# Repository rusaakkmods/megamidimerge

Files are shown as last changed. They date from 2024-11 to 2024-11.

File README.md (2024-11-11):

# rusaaKKMODS Megamidi Merge
================

A MIDI merge project for Arduino.

## Overview
-----------

This project is designed to merge MIDI input from multiple sources, calculate beats per minute (BPM), and update clock resolution as needed.

### Features
------------

* Merges MIDI input from two sources (MIDI-1 and MIDI-2)
* Calculates BPM from MIDI clock messages
* Updates clock resolution based on user input
* Displays current BPM, clock resolution, and master clock source on an OLED display

### Functions
-------------

* `initMidi()`: Initializes MIDI input and output interfaces.
* `calculateBPM()`: Calculates the current BPM from MIDI clock messages.
* `changeClockResolution()`: Updates the clock resolution based on user input.
* `readMidiInput()`: Reads and processes MIDI input from both sources.
* `printDisplay()`: Prints the current display information, including master clock source, BPM, and clock resolution.
* `isMasterInput1()`: Checks if the master clock source is set to MIDI-1.
* `loop()`: The main loop function that updates BPM, checks for user input, and reads MIDI input.

### Dependencies
------------

* Arduino library (for `millis()` and `digitalRead()` functions)
* MIDI library (for MIDI input and output handling)

### Hardware Requirements
----------------------

* Arduino board (e.g. Arduino Mega)
* MIDI input and output interfaces
* OLED display
* Push button for changing clock resolution

### Usage
-----

1. Upload the sketch to the Arduino board.
2. Connect the MIDI input and output interfaces to the board.
3. Connect the OLED display to the board.
4. Press the push button to change the clock resolution.

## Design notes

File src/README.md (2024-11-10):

Based on the code we currently have, let's review the main goals and assess the progress:

### Main Goals:

1. **Core Function: Merges MIDI data from two MIDI inputs and sends it to MIDI output**

   - **Status**: Achieved. The code reads MIDI messages from `MIDIINPUT1` and `MIDIINPUT2` and merges them into a single output (`MIDIOUTPUT`). MIDI messages are forwarded appropriately to combine data from both inputs.

2. **Master Clock Selection: An SPDT switch allows you to choose which MIDI input provides the master clock**

   - **Status**: Achieved. The function `isMasterInput1()` reads the state of the master switch (`MASTER_SWITCH_PIN`) to determine which MIDI input is the master clock source. This condition is used throughout the code to determine the active master.

3. **Analog Clock Output: Generates an analog clock signal synchronized with the MIDI clock**

   - **Status**: Achieved. The function `generateDigitalClockPulse()` is responsible for outputting a pulse on the clock output pin (`CLOCK_OUT_PIN`). However, software-based timing could be less precise, and switching to hardware-based timers for pulse generation is recommended.

4. **Clock Pulse Rate: A knob to control the clock pulse per quarter note (1 to 24 ppqn) for the analog clock output**

   - **Status**: Achieved. The knob input (`RESOLUTION_KNOB_PIN`) is read and mapped to different pulse-per-quarter-note values using the `handleClockOut()` function. The mapped values are snapped to specific options, which align with the requirements.

5. **Active Master Input Display: Shows the active MIDI Input acting as the Master Clock on an OLED display**

   - **Status**: Achieved. The function `printDisplay()` updates the OLED display with information about which input is the active master, depending on the `isMasterInput1()` function result. It also displays BPM and clock rate settings.

6. **BPM Display: Displays the Beats Per Minute (BPM) in 4/4 time signature based on selected master clock**

   - **Status**: Achieved. The function `calculateBPM()` calculates the BPM based on the `clockCount`, and `handleDisplay()` updates the OLED display every second with the calculated BPM.

7. **Clock Rate Display: based on the selected resolution setting**

   - **Status**: Achieved. The function `printDisplay()` shows the clock rate and provides an indicator for the current pulse-per-quarter-note value. The `resolution` variable is used for determining and displaying the current setting.

8. **Analog Clock Input: Override MIDI master clock**

   - **Status**: Achieved. The `handleClockIn()` function manages clock input detection. When a clock pulse is detected on `CLOCK_IN_PIN`, it sets `clockInputPulse` and sends a MIDI clock message (`sendRealTimeMessage(midi::Clock)`), effectively overriding the MIDI master clock.

### &#x20;Features:

1. **2 MIDI Inputs (as Input 1 and Input 2)**

   - **Status**: Achieved. The code uses `Serial1` and `Serial2` as MIDI inputs, which are then processed and forwarded as needed.

2. **2 MIDI Thru (from MIDI Input 1 and MIDI Input 2)**

   - **Status**: Implicitly Achieved. The messages from `MIDIINPUT1` and `MIDIINPUT2` are forwarded, effectively acting as MIDI Thru functionality.

3. **A MIDI Output (Merged from both MIDI Inputs)**

   - **Status**: Achieved. The merged MIDI messages are sent to `MIDIOUTPUT`.

4. **A 3.5mm TRS Socket as a second MIDI Output (independent copy of the first MIDI Output)**

   - **Status**: Not explicitly mentioned in the code. If this feature is still desired, it may need additional implementation, likely involving copying the `MIDIOUTPUT` to another UART or pin.

5. **Analog Clock Out based on Master clock**

   - **Status**: Achieved. The clock output is generated using software-based timing (`generateDigitalClockPulse()`), but improvements to use hardware timers are recommended for better precision.

6. **Analog Clock In that overrides the MIDI Clock when plugged**

   - **Status**: Achieved. The `handleClockIn()` function detects clock input pulses and overrides the MIDI clock when active.

7. **A Master Clock switch between Input 1 or Input 2**

   - **Status**: Achieved. The function `isMasterInput1()` reads the `MASTER_SWITCH_PIN` to determine which input is the master clock.

8. **A Knob to control Clock Out PPQN**

   - **Status**: Achieved. The `RESOLUTION_KNOB_PIN` is used to set the clock rate (`resolution`), which affects the pulse-per-quarter-note value.

9. **USB should power the system and should be recognized by Computer as MIDI Device transmitting merged MIDI Output**

   - **Status**: Not explicitly Achieved. The code does not mention USB MIDI functionality. To achieve this, additional USB-MIDI code would need to be implemented to allow the Arduino to act as a USB MIDI device.

10. **An OLED Display to view Active Master information**

    - **Status**: Achieved. The `printDisplay()` function displays the current master clock source, BPM, and clock rate settings on the OLED.

### Summary of Improvements:

- **Precision for Clock Output**: Consider using hardware timers for generating clock pulses (`generateDigitalClockPulse()`) to improve accuracy.
- **USB MIDI Functionality**: If USB MIDI is required, additional implementation is necessary.
- **Refactor Complex Functions**: Functions like `forwardMessage()` are handling many different cases, and breaking them into smaller functions would improve readability and maintainability.
- **Analog Read Noise Filtering**: Adding noise filtering or averaging to `analogRead(RESOLUTION_KNOB_PIN)` can help stabilize the value and avoid erratic changes in clock rate.

Overall, the core functionality has been achieved, with some areas for improvement in terms of precision, maintainability, and additional desired features like USB MIDI support.

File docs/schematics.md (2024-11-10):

### Bill of Materials (BOM):

1. **Arduino Mega 2560 Pro**

   - Quantity: 1
   - Acts as the main controller.

2. **5-pin DIN MIDI Ports**

   - Quantity: 6&#x20;
   - for 2 MIDI Inputs, 2 MIDI Thru, 2 MIDI Outputs

3. **3.5mm TRS Jack**

   - Quantity: 2
   - for MIDI Outputs

4. **6N137 Optocoupler**

   - Quantity: 2&#x20;
   - for MIDI Input isolation

5. **Current-Limiting Resistors**

   - 220 ohms: Quantity: 4 (MIDI Input LED and Output TX)
   - 10k ohms: Quantity: 2 (Optocoupler pull-up)

6. **LM393 Comparator or 74HC14**

   - Quantity: 1 (for Analog Clock pulse generation)

7. **OLED Display (128x32, I2C)**

   - Quantity: 1
   - Used to display active master, BPM, etc.

8. **Potentiometer (for PPQN Selection)**

   - Quantity: 1
   - Type: 10k linear potentiometer

9. **SPDT Switch**

   - Quantity: 1
   - Type: Toggle or slide switch

10. **TS Jack (for Analog Clock Input)**

    - Quantity: 1

11. **Capacitors**

- 100µF: Quantity: 1 (Power Supply Stabilization)
- 0.1µF Ceramic: Quantity: 4 (Decoupling capacitors for ICs)

11. **PWM Output Components**

- **Voltage Divider Resistors**: Various values depending on desired voltage.
- **Comparator Potentiometer**: Quantity: 1 (to set threshold for LM393)

12. **Miscellaneous**

- **Wires**: Jumper wires for connections.
- **Breadboard**: Optional, for prototyping.
- **Pull-up Resistors**: Quantity: 2 (10k ohms for switches).

### Components in the Project:

1. **Arduino Mega 2560 Pro**:

   - Acts as the main controller.
   - Handles MIDI inputs, MIDI merging, and MIDI output.

2. **MIDI Ports (DIN connectors or TRS jacks)**:

   - **MIDI Input 1** and **MIDI Input 2**: Receive MIDI signals.
   - **MIDI Thru 1** and **MIDI Thru 2**: Allow direct forwarding of incoming MIDI signals.
   - **MIDI Output**: Outputs the merged MIDI messages.

3. **MIDI Input Circuit**:

   - Typically involves **6N137** optocouplers for MIDI signal isolation.
   - **Current-limiting resistors** are needed for safe data transmission.

4. **Analog Clock Circuit**:

   - Outputs clock signals synchronized with the master MIDI clock.
   - **LM393 comparator** or **74HC14** for generating pulses, using the analog clock signal.

5. **OLED Display (I2C, 128x32)**:

   - Used for displaying the active master, BPM, clock rate, etc.
   - Connected through I2C using **SCL** and **SDA** pins.

6. **Knob for PPQN Selection (Potentiometer)**:

   - Used to select the clock rate.
   - **Connected to an analog input** of the Arduino for reading the resistance value.

7. **SPDT Switch for Master Clock Selection**:

   - Switches between MIDI Input 1 and MIDI Input 2 as the clock source.
   - Connected to a digital input.

8. **Clock Input Circuit**:

   - Analog clock input that overrides the MIDI clock.
   - **TS jack** with clock input detection and routing.
   - Typically uses an interrupt for detecting pulses.

### Detailed Schematic Overview:

#### 1. **Arduino Mega 2560 Pro**:

- **Power Supply**: USB or external power supply. Make sure to add capacitors (e.g., 100µF and 0.1µF) for stability.
- **MIDI Ports**:
  - **MIDI Input**: Connect each input through a 220-ohm resistor to the anode of an LED (inside a 6N137 optocoupler). The cathode of the LED goes to ground via a current-limiting resistor (typically 220 ohms). The 6N137 output is pulled up (typically 10k ohms) and then connected to the Arduino RX pin.
  - **MIDI Output**: The output from the Arduino TX pin goes through a 220-ohm resistor to pin 4 of the MIDI output connector, with pin 5 connected to ground.

#### 2. **MIDI Input Circuit** (using **6N137** optocouplers):

- **6N137 Pin Configuration**:
  - **Pin 1**: Vcc (connected to 5V through a current-limiting resistor)
  - **Pin 2 (Anode)**: Connected to MIDI Input through a 220-ohm resistor.
  - **Pin 3 (Cathode)**: Connected to GND.
  - **Pin 4 (GND)**: Connected to GND.
  - **Pin 5 (Output)**: Connected to Arduino RX pin, pulled up to 5V through a 10k resistor.
  - **Pin 6 (NC)**: Not connected.
  - **Pin 7 (Vcc)**: Connected to 5V.
  - **Pin 8 (GND)**: Connected to GND.

#### 3. **OLED Display**:

- **SDA**: Connected to Arduino **SDA** (typically A4 for Mega).
- **SCL**: Connected to Arduino **SCL** (typically A5 for Mega).
- **VCC**: Connected to 3.3V or 5V.
- **GND**: Connected to GND.

#### 4. **Knob for PPQN Selection**:

- **Potentiometer**:
  - One terminal to **GND**.
  - One terminal to **5V**.
  - The wiper (middle terminal) to an analog input pin (e.g., **A0**).

#### 5. **SPDT Switch**:

- One side connected to **5V**.
- The other side connected to **GND**.
- The middle pin is connected to a digital input pin (e.g., **D7**), with a **pull-up resistor** enabled to detect the switch state.

#### 6. **Analog Clock Input Circuit**:

- **TS Socket Pinout**:
  - **Tip**: Clock input signal.
  - **Ring**: Connect to **Tip** when unplugged to detect.
  - **Sleeve**: Ground.
- The **Tip** is connected to the **CLOCK\_IN\_PIN** via a current-limiting resistor, with an **interrupt** configured on this pin to detect rising edges.
- The **Ring** is used to detect if the clock is plugged in by connecting it to an additional digital pin that can be read.

#### 7. **Analog Clock Output Circuit**:

- **PWM Output (Pin 10)**: Use this pin to generate an analog voltage that is converted to pulses using a comparator.
- **Comparator LM393**:
  - **Non-inverting Input (+)**: Connected to the **PWM output pin** through a voltage divider.
  - **Inverting Input (-)**: Set with a threshold voltage using a potentiometer or resistor divider.
  - **Output**: Generates the clock pulse based on the threshold comparison.
- The output is then connected to the **Clock Out** TS socket.

### General Tips:

- **Power Rails**: Ensure decoupling capacitors are placed near every IC to reduce noise (e.g., 0.1µF ceramic capacitors).
- **Grounding**: Make sure all ground connections are common to avoid ground loops that can introduce noise.
- **Pull-up/Pull-down Resistors**: Properly use pull-up or pull-down resistors where required to ensure the stability of input signals, such as the switch or plug detection.

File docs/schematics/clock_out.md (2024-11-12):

### Review of Clock Output Schematic

#### **MEGA PIN 10 Connection**:
- The clock signal from **MEGA PIN 10** is correctly fed into the circuit, passing through **R19 (10kΩ)**, which acts as a current-limiting resistor. This is appropriate for preventing potential current surges into the next stage.

#### **Capacitor (C13 - 1µF)**:
- **C13 (1µF)** is placed in series after **R19** and connected to **GND** via **R20 (10kΩ)**, forming an RC filter.
- This configuration helps eliminate any noise in the clock signal before it is passed to the **74HC14** Schmitt Trigger, ensuring a stable and clean clock signal.
- The **1µF capacitor** and the **10kΩ resistor (R20)** give a cutoff frequency of approximately **16 Hz**, which should be effective for filtering out high-frequency noise without affecting the clock pulse.

#### **Schmitt Trigger Inverters (U4E, U4F - 74HC14)**:
- The **74HC14** Schmitt Trigger is used here, with **U4E** and **U4F** used for conditioning the clock signal.
- The clock signal is fed into **U4E**, which outputs a clean, inverted pulse. This signal is then sent to **J11 (Clock Out 1)** through **R21 (220Ω)**.
- The same input signal is also fed to **U4F**, which provides an additional clean output to **J12 (Clock Out 2)** through **R22 (220Ω)**.
- Using the **74HC14** for clock conditioning is an excellent choice, as it ensures a crisp, debounced clock pulse suitable for driving external clock inputs.

#### **Clock Output Jacks (J11, J12)**:
- **J11** and **J12** are used for clock outputs, each being fed from one of the Schmitt Trigger outputs through the corresponding output resistor (**R21** and **R22**, both **220Ω**).
- The **Tip (T)** of each jack is driven by the respective Schmitt Trigger output, while the **Sleeve (S)** is connected to **GND**.
- The **TN** connection on each jack is left unconnected, which is fine as it’s not needed for the clock signal.
- This setup is suitable for providing two identical clock signals, with **74HC14** outputs ensuring that they are clean and debounced.

### **Suggestions for Improvement**:

1. **Pull-down Resistors on Schmitt Trigger Inputs**:
   - It might be beneficial to add small pull-down resistors (e.g., **10kΩ**) to the inputs of **U4E** and **U4F** to ensure that they remain at a defined logic level if the input signal from **MEGA PIN 10** becomes disconnected. This helps prevent the Schmitt Trigger from floating, which could lead to unpredictable behavior.

### **Summary**:
- The schematic design is **correct** and should work effectively for generating two clock outputs from **MEGA PIN 10**.
- The use of **R19**, **C13**, and **R20** to filter the input and the **74HC14** Schmitt Trigger to clean up the clock signal are well-considered.
- Adding **pull-down resistors** to the **74HC14** inputs would further improve the reliability and robustness of the circuit.

This design is well-structured and should provide stable clock outputs. Let me know if you need further assistance or modifications!

Modifications:
Based on your updated schematic, here is my review:

1. **Component Placement and Value**:
   - The capacitors C14 and C15 (10nF) are well-placed for filtering purposes, which helps reduce noise and ensures stable clock output. Using these capacitors to filter the signal before it reaches the 74HC14 input and before driving the MIDI connectors is a good practice.
   - The resistor values seem correct for this type of application, particularly for providing current limiting to the outputs and pull-down where needed.

2. **74HC14 Usage**:
   - The 74HC14 Schmitt Trigger inverter (U4E and U4F) is appropriate here, as it will help to clean up the incoming signal from the Mega pin and ensure it has proper transitions. The Schmitt Trigger is ideal to eliminate noise from the clock pulse and ensure a stable square wave for the MIDI Clock output.

3. **Clock Outputs (J11 and J12)**:
   - The use of 220Ω resistors (R21 and R22) before the MIDI output connectors is good for limiting current, which helps to protect the 74HC14 output and meet MIDI current specifications.

4. **Decoupling Capacitors**:
   - Adding decoupling capacitors close to the power pins of the 74HC14 would be a good improvement if not already present. Typically, a 0.1 µF capacitor between Vcc and GND pins helps to filter any noise on the power line, ensuring reliable operation of the IC.

5. **Potential Improvement**:
   - Ensure that C13 (1µF) and R19/R20 (both 10kΩ) are appropriately tuned to avoid any unintended delay or filtering of the clock pulse. The RC combination acts as a filter, so it's important that the values are selected to preserve the desired pulse timing characteristics.
   - The capacitors C14 and C15 (10nF) also add filtering at the output. Just make sure they are tuned in such a way that the pulse shape still matches what you need for MIDI communication, which requires fast transitions.

The overall design looks well-planned for a reliable MIDI clock output circuit. Just consider double-checking the timing to make sure that none of the RC filtering affects the precision of the clock signal that’s critical in MIDI timing.

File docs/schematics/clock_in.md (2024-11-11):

### Review of Updated Clock In Schematic

This updated schematic looks well-optimized and includes all the important elements for both input protection and reliable plug detection. Here’s a review:

#### **Jack (J10 - Clock In)**:
- The **Tip (T)** is correctly connected to **MEGA PIN 3** through **R18**.
- **Sleeve (S)** is connected to **GND** for proper grounding, and **TN** is also connected to **T** when unplugged, which allows for plug detection functionality.
  
#### **Current Limiting Resistor (R18 - 220Ω)**:
- The addition of **R18 (220Ω)** in series between **pin T** of **J10** and **MEGA PIN 3** is an excellent addition for protecting **MEGA PIN 3** from any excessive current.
- This provides the necessary safety without affecting the functionality of clock pulse detection.

#### **Voltage Divider for Plug Detection (R16, R17)**:
- **R17 (10kΩ)** and **R16 (10kΩ)** form a voltage divider providing a stable reference voltage for **MEGA PIN A1**.
- This is sufficient to differentiate between the plug being connected and disconnected, allowing the microcontroller to detect the plug status reliably.

#### **Noise Filtering Capacitor (C12 - 0.1µF)**:
- **C12 (0.1µF)** is placed correctly between the voltage divider and **GND**, helping to eliminate high-frequency noise and ensuring stable readings on **MEGA PIN A1**.

### **Suggestions**:
- The current configuration now provides the necessary safety (via **R18**) and a stable voltage reference for plug detection.
- Ensure the voltage at **MEGA PIN A1** is well-tested to confirm it provides consistent readings under both conditions (plug connected vs. disconnected). The **10kΩ** resistors should work well, but testing might indicate if a slight adjustment is needed.

### **Summary**:
- The addition of **R18 (220Ω)** makes this schematic well-protected.
- The plug detection functionality is intact, with **R16**, **R17**, and **C12** providing stable operation.
- This circuit now effectively protects the microcontroller inputs and reliably differentiates between plug states.

This design should be ready for implementation. Great work! If you need further assistance or modifications, feel free to ask!

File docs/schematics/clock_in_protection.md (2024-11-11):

### Clock In Surge Protection Improvement

To add safety measures for the **Clock In (J10)** circuit to protect against high currents and voltage spikes, we have made the following improvements:

#### **Components and Their Values**:
- **J10 (Clock In Jack)**: The input jack for external clock signals.
- **R18**: **220Ω current limiting resistor** in series.
- **D1 (1N5819 Schottky Diode)**: To clamp any overvoltage to **GND**.
- **D2 (1N5819 Schottky Diode)**: To clamp any overvoltage to **5V**.
- **F1**: **50mA polyfuse** for overcurrent protection.

#### **Detailed Schematic Pinout Routing**:

1. **Clock In Jack (J10)**:
   - **Pin T (Tip)** of **J10**:
     - **Connect to R18** (220Ω current limiting resistor).
   - **Pin S (Sleeve)** of **J10**:
     - **Connect to GND**.
   - **Pin TN (if present, not used for routing)**.

2. **Current Limiting Resistor (R18 - 220Ω)**:
   - **One end connected to Pin T** of **J10**.
   - **The other end connected to MEGA PIN 3**.
   - This resistor limits the current flowing into **MEGA PIN 3**.

3. **Polyfuse (F1 - 50mA)**:
   - **Connect F1 in series** with **R18** between **Pin T** and **MEGA PIN 3**.
   - This provides protection against sustained overcurrent.

4. **Schottky Diodes (D1 and D2 - 1N5819)**:
   - **D1**: Voltage Clamping to **GND**:
     - **Anode** of **D1** connected to **GND**.
     - **Cathode** of **D1** connected to the node where **R18** and **F1** connect to **MEGA PIN 3**.
     - This clamps any negative voltage spikes to protect **MEGA PIN 3**.
   - **D2**: Voltage Clamping to **+5V**:
     - **Anode** of **D2** connected to the node where **R18** and **F1** connect to **MEGA PIN 3**.
     - **Cathode** of **D2** connected to **+5V**.
     - This clamps any voltage above **5V** to the **5V rail**, protecting **MEGA PIN 3** from overvoltage.

5. **MEGA PIN 3**:
   - The connection from **R18** (after going through the **polyfuse**) connects to **MEGA PIN 3** for **clock pulse detection**.
   - **MEGA PIN 3** should also be configured as an **input** with either an internal or external **pull-up resistor** to maintain a stable state when no signal is connected.

#### **Explanation**:
- **R18 (220Ω)**: Limits the current from **pin T** of **J10** to **MEGA PIN 3**, ensuring the current remains within safe limits.
- **F1 (50mA Polyfuse)**: Provides overcurrent protection and disconnects the circuit if a sustained overcurrent condition occurs.
- **D1 (1N5819)**: Protects **MEGA PIN 3** from any **negative voltage spikes** by clamping to **GND**.
- **D2 (1N5819)**: Protects **MEGA PIN 3** from **positive overvoltage** spikes above **5V** by clamping to the **5V rail**.

#### **Summary**:
- The **current limiting resistor (R18)** and **polyfuse (F1)** together ensure that **MEGA PIN 3** is protected against high current conditions.
- The **Schottky diodes (D1 and D2)** provide protection against overvoltage and negative voltage spikes, clamping the signal to a safe range.
- This setup adds robustness to the **Clock In** circuitry and helps to prevent damage to the microcontroller.

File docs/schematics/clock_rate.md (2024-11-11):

### Clock Rate Knob Review

Clock Rate Knob Schematic

#### **Review of the Updated Clock Rate Knob**:

1. **Potentiometer (RV1) Configuration**:
   - The **10kΩ linear potentiometer (RV1)** is still correctly configured as a **voltage divider** between **+5V (Pin 3)** and **GND (Pin 1)**.
   - The **wiper (Pin 2)** is connected to **MEGA PIN A0**, providing a variable voltage to be read by the Arduino.

2. **Bypass Capacitor (C8)**:
   - You have added a **0.1µF capacitor (C8)** between the **wiper (Pin 2)** and **GND**. This is a great addition for filtering out any noise.
   - This capacitor acts as a **low-pass filter**, smoothing the signal read by **MEGA PIN A0**. It will reduce any high-frequency noise and provide a more stable analog voltage, thereby improving the accuracy of the clock rate adjustments.

3. **Voltage Range and Stability**:
   - With the **bypass capacitor (C8)** in place, the voltage range remains from **0V to 5V**, and the capacitor helps in filtering any small fluctuations, which results in a much more stable output to **MEGA PIN A0**.

#### **Suggestions for Further Improvement**:

- **Potentiometer Quality**:
  - Ensure the **potentiometer** used is of good quality, with smooth rotation and minimal contact noise, to avoid jitter in the clock rate readings.

- **PCB Layout Considerations**:
  - Place the **capacitor (C8)** as close as possible to **MEGA PIN A0** and the potentiometer's wiper pin to minimize the length of the trace, which will help reduce noise pickup.

#### **Summary**:

- The addition of the **0.1µF capacitor (C8)** is an excellent improvement. It provides a smoother analog signal, reducing noise and jitter in the clock rate adjustment.
- This configuration, with the potentiometer as a **voltage divider** and the **bypass capacitor**, should provide reliable and stable clock rate control for your MIDI device.

Overall, this updated design should function very well for adjusting the clock rate with minimal noise and jitter. Great work on incorporating the suggested improvement!

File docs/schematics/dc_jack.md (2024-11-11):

### DC Input Schematic Review

DC Input Schematic

#### **Review of the DC Input Schematic**:

1. **DC Jack (J9) Configuration**:
   - The **DC Jack (J9)** is appropriately labeled for **9V DC input**.
   - **Pin 1** (center positive) is correctly routed through the **fuse (F1)** and **Schottky diode (D11)** to the **VIN pin** of the Arduino MEGA.
   - **Pin 2** (outer sleeve) is connected to **GND**, completing the power connection.

2. **Protection Components**:
   - **Fuse (F1 - 1A)**:
     - The **fuse** is correctly placed in series with the positive terminal of the DC jack. This provides overcurrent protection and ensures the circuit is safeguarded from short circuits or excessive current draw.
   - **Schottky Diode (D11 - 1N5819)**:
     - The **Schottky diode** is in the correct orientation, with the **anode** connected to the positive terminal of the DC jack and the **cathode** connected to the **VIN** pin of the MEGA.
     - This configuration provides **reverse polarity protection** in case the DC adapter is accidentally connected with incorrect polarity. The **1N5819** is a good choice, as it has a low forward voltage drop, reducing power loss.

3. **Decoupling Capacitors**:
   - **Capacitor C10 (0.1µF Ceramic)**:
     - This capacitor is correctly placed across **VIN** and **GND**. It is effective at filtering out high-frequency noise.
   - **Capacitor C11 (100µF Electrolytic)**:
     - This capacitor is also correctly placed across **VIN** and **GND**, providing good low-frequency filtering and helping to smooth out the voltage from the DC adapter.
   - The combination of **C10** and **C11** is effective for ensuring a clean and stable input voltage to the Arduino MEGA.

#### **Suggestions for Improvement**:

1. **Fuse Rating**:
   - The **1A fuse** should be suitable for most Arduino MEGA applications, but if you are powering multiple peripherals that draw significant current, you may consider increasing the fuse rating to **1.5A** or **2A**, depending on the actual current draw.

2. **Heat Dissipation**:
   - The **Schottky diode (D11)** will dissipate some heat depending on the current passing through it. Although **1N5819** has a low forward voltage drop, if you are drawing significant current, consider using a **heatsink** or ensuring there is adequate airflow to prevent overheating.

3. **PCB Layout Considerations**:
   - When laying out the PCB, ensure that the **capacitors (C10 and C11)** are physically placed close to the **VIN pin** of the MEGA to maximize their effectiveness.
   - The **fuse (F1)** should be easily accessible so that it can be replaced if it blows.

#### **Summary**:

- The **DC input design** is correct and effectively incorporates protection and filtering components to provide a safe and stable power supply to the **Arduino MEGA**.
- **F1** provides **overcurrent protection**, and **D11** ensures **reverse polarity protection**, both of which are essential for safeguarding the circuit.
- The **decoupling capacitors (C10 and C11)** are well-placed to filter the incoming power supply and reduce noise, ensuring stable operation of the MEGA.

This design should work well for safely powering your Arduino MEGA from a **9V DC adapter**. Great job on incorporating all the recommended protection and filtering components!

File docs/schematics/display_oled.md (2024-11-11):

### OLED Display Interface Review

OLED Display Schematic

#### **Review of the Updated OLED Display Interface**:

1. **I2C Connection**:
   - The **SSD1306 OLED** remains connected to the **MEGA SDA** and **SCL** pins for I2C communication.
   - **4.7kΩ pull-up resistors (R14 and R15)** are still connected between **SDA/SCL** and **+5V**, which helps to pull the I2C lines high during idle periods.

2. **Power Supply Connections**:
   - **VCC (Pin 2)** is correctly connected to **MEGA 5V**.
   - **GND (Pin 1)** is connected to **ground**, completing the power supply circuit.

3. **Decoupling Capacitor (C9)**:
   - The addition of the **0.1µF capacitor (C9)** across the **VCC and GND** pins is an excellent addition.
   - This capacitor helps filter out noise on the power supply line, providing a more stable voltage to the OLED, which is particularly useful for ensuring reliable operation in digital circuits.

#### **Suggestions for Further Improvement**:

1. **I2C Pull-Up Resistors**:
   - As previously mentioned, the **4.7kΩ** pull-up resistors are appropriate for general I2C usage. However, if you are using the I2C bus at a high speed (e.g., **400kHz**), you might consider lowering them to **2.2kΩ** or **3.3kΩ** to ensure faster signal rise times.

2. **Trace Lengths**:
   - Keep the **SDA** and **SCL** lines as short as possible to reduce the risk of signal degradation or noise interference. This is particularly important for I2C signals.

#### **Summary**:

- The addition of the **0.1µF capacitor (C9)** across **VCC** and **GND** is a great improvement. It helps stabilize the power supply to the OLED and reduces noise, which will ensure more reliable operation.
- The **I2C pull-up resistors** are suitable, but depending on the speed of communication and bus length, you could optimize their values for improved performance.
- The rest of the connections are well done, ensuring a proper power supply and stable I2C communication.

This updated design should provide stable communication with the **OLED Display**, ensuring reliable operation in the presence of potential electrical noise. Great job on incorporating the improvements!

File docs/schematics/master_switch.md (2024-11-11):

### Master Clock Switch Review

Master Clock Switch Schematic

#### **Review of the Master Clock Switch**:

1. **Switch (SW1) Configuration**:
   - The **Master Clock Switch (SW1)** is configured as a **SPDT (Single Pole Double Throw)** switch.
   - It appears that the **switch** is used to select between different clock sources, with **Pin 7 of the MEGA** reading the selected clock input.

2. **Power Supply and Input Signal**:
   - The switch is connected to **+5V** on **Pin 3** of SW1.
   - The **common terminal (Pin 2)** is routed to **MEGA Pin 7**, which will act as the input signal for the clock selection.
   - **Pin 1** is connected to ground through the **capacitor (C7)**, allowing the switch to pull the signal to **ground** depending on its position.

3. **Debouncing Circuit**:
   - You have a **10nF capacitor (C7)** connected in parallel with a **10kΩ resistor (R13)** between **Pin 7 of the MEGA** and **GND**.
   - This combination acts as a simple **debouncing circuit** to reduce noise caused by mechanical switch contacts.
   - The **10nF capacitor** provides a short charge/discharge time, effectively filtering out any rapid fluctuations due to switch bounce.
   - The **10kΩ pull-down resistor (R13)** ensures that the input pin on the MEGA is pulled to ground when the switch is open, preventing floating inputs.

#### **Suggestions for Improvement**:

1. **Debouncing**:
   - The **10nF capacitor** and **10kΩ resistor** should work well for debouncing in most applications. However, if you notice any instability or bounce issues, you could adjust the capacitor value to **22nF** or the resistor value to **5kΩ** to fine-tune the debounce timing.
   - If additional precision is required for debouncing, consider implementing a **software debounce** algorithm to complement this hardware setup.

2. **Input Protection**:
   - Although the current setup is quite stable, you may consider adding a **small series resistor (e.g., 100Ω)** between **Pin 7** of the MEGA and the switch output. This resistor can help protect against any transient currents or voltage spikes caused by mechanical switching.

3. **Switch Contact Quality**:
   - Ensure that the **switch (SW1)** is a high-quality component with low contact bounce. Using a switch with gold-plated contacts can reduce the likelihood of noise and bounce, further improving stability.

4. **PCB Layout Considerations**:
   - When placing these components on a PCB, ensure that the **capacitor (C7)** is located physically close to **Pin 7** of the MEGA to reduce potential noise pickup on the signal line.
   - Keep the traces for **SW1** and **R13** short and direct to minimize noise susceptibility.

#### **Summary**:

- The **Master Clock Switch** is well-configured, and the debouncing circuit should effectively reduce mechanical noise from the switch.
- The use of a **10nF capacitor** and **10kΩ pull-down resistor** is appropriate for most debounce needs, but minor adjustments could be made if needed based on observed performance.
- Adding a **small series resistor** could provide an extra layer of protection to the MEGA input pin.

This setup should provide a reliable means of switching between clock sources while minimizing bounce issues and ensuring clean input signals to the MEGA. Let me know if you need further guidance or have additional questions about this design!

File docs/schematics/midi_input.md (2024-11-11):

### MIDI Input Schematics Review

#### **Review of the Changes**:

1. **Pull-Up Resistor Update**:

   - You’ve replaced **R4** with a **4.7kΩ** resistor connected to **5V**, consistent with **R2**. This is the ideal configuration for compatibility with the **Arduino MEGA** logic levels. It ensures both MIDI inputs have robust and reliable pull-up to 5V.

2. **Capacitor Placement and Values**:

   - The **10pF capacitors (C1, C3)** are placed across the optocoupler's anode and cathode, providing high-frequency noise suppression. This positioning will help to eliminate noise before the signal reaches the **6N137** optocoupler, improving the stability of the input signal.
   - The **decoupling capacitors (C2, C4)** are still correctly placed between **5V and GND** to filter noise from the power supply, helping to ensure stable operation of the optocouplers.

3. **General Layout**:

   - The **diode network** and **optocoupler** placement are clear and follow good design practices.
   - **Schottky diodes (D2, D4)** and **Zener diodes (D1, D3)** are effectively used to provide robust protection for both MIDI input lines. The combination ensures that both overvoltage and reverse current are managed properly.

#### **Final Suggestions**:

- **PCB Layout Considerations**:

  - When routing the PCB, try to place the **decoupling capacitors (C2, C4)** as close to the **Vcc and GND pins** of each **6N137** optocoupler as possible. This will maximize their effectiveness.
  - Ensure that there is a solid **ground plane** under the MIDI input section. This will help in reducing noise and provide better **EMI shielding**.

- **Power Supply Lines**:

  - Keep the **power supply lines** to the optocouplers and the **5V pull-up resistors** as short as possible. This will reduce any noise pick-up from these lines.

- **Test the Filtering Capacitor**:

  - The **10pF capacitor** should ideally reduce high-frequency noise without affecting the MIDI signal. However, in case of unexpected behavior (such as missing MIDI messages), you might experiment with the capacitor value between **10pF to 22pF** to find the most optimal noise suppression for your environment.

#### **Summary**:

Schematic is well-optimized for handling MIDI inputs with proper noise suppression and signal integrity. The changes made—updating pull-up resistors to 4.7kΩ tied to 5V, adding small capacitors for filtering, and ensuring consistent protection with Zener and Schottky diodes—result in a solid design.

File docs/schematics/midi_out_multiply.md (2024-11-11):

### Multiply MIDI Output Schematic Design

#### **Design Overview**

To multiply the output of **Serial3** from the Arduino into **4 MIDI Outputs**, the following design uses a **6N137 optocoupler** to isolate the original signal and a **74HC14** buffer IC to distribute the isolated signal to four MIDI outputs. This ensures strong signal integrity and electrical isolation.

#### **Components Needed**

- **6N137 Optocoupler**: For isolating the Serial3 signal.
- **Logic Buffer IC (74HC14)**: For distributing the isolated MIDI signal to four outputs.
- **Current-Limiting Resistors (220Ω)**: On each MIDI output line to adhere to the MIDI standard.
- **Pull-Up Resistor (4.7kΩ)**: For the output of the 6N137 to ensure proper logic levels.
- **Schottky Diodes (1N5819)**: For protection on each MIDI output line.
- **Decoupling Capacitors (0.1µF)**: To filter out noise on the power supply lines.
- **TRS Jacks**: For MIDI OUT 3 and MIDI OUT 4.

#### **Step-by-Step Schematic Description**

1. **Input from Serial3 TX**:

   - Connect the **TX pin from Serial3** to the **anode** of the LED in the **6N137 optocoupler** through a **220Ω current-limiting resistor**.
   - The **cathode** of the LED should be connected to **ground**.

2. **6N137 Optocoupler**:

   - **Pin 2 (Anode)**: Connect to **TX Serial3** via a **220Ω resistor**.
   - **Pin 3 (Cathode)**: Connect to **GND**.
   - **Pin 8 (Vcc)**: Connect to **+5V** with a **0.1µF capacitor** placed nearby for decoupling.
   - **Pin 5 (Output)**: This is the optically isolated output. Connect a **4.7kΩ pull-up resistor** from **pin 5** to **+5V**.
   - **Pin 6 (Enable)**: Tie to **GND** to enable the output of the optocoupler.

3. **Buffered Fan-Out Stage: Complete Pinout Using 74HC14**

   - Use a **74HC14** (Schmitt Trigger Inverter) to fan out the isolated MIDI signal to the four MIDI outputs.
   - **Input to Buffer IC**: Connect the output from the **6N137 (Pin 5)** to **Pin 1 (Input A)** of the **74HC14**.
   - **Output Pins of Buffer IC**: Use the following output pins to connect to the MIDI Outputs:
     - **Pin 2** (Output of Inverter A) to **MIDI OUT 1**.
     - **Pin 4** (Output of Inverter B) to **MIDI OUT 2**.
     - **Pin 6** (Output of Inverter C) to **MIDI OUT 3**.
     - **Pin 8** (Output of Inverter D) to **MIDI OUT 4**.
   - **Input Pins for Remaining Inverters**:
     - Tie the unused **input pins (3, 5, 9, 11, 13)** of the **74HC14** to **GND** to prevent floating inputs and potential noise issues.

4. **MIDI Output Connections** (for each of the 4 MIDI Outputs: Detailed Pinout):

   - **MIDI OUT 1 and MIDI OUT 2 (DIN Jacks)**:
     - **Pin 4 of MIDI Jack**:
       - Connect the output from the buffer IC through a **220Ω resistor**.
       - For example, connect **Pin 2** of the **74HC14** to **Pin 4** of **MIDI OUT 1** through a **220Ω resistor**.
     - **Pin 5 of MIDI Jack**:
       - Connect to **GND**.
     - **Pin 2 of MIDI Jack** (Shield Connection):
       - Connect to **GND** to provide shielding and reduce noise.
     - **Protection Diode**:
       - Add a **Schottky diode (1N5819)** between **Pin 4** (output) and **GND** with the cathode connected to **Pin 4** to provide reverse current protection.

   - **MIDI OUT 3 and MIDI OUT 4 (TRS Jacks)**:
     - **Tip (T)**: Connect the output from the buffer IC through a **220Ω resistor**.
       - For **MIDI OUT 3**, connect **Pin 6** of the **74HC14** to **Tip** through a **220Ω resistor**.
       - For **MIDI OUT 4**, connect **Pin 8** of the **74HC14** to **Tip** through a **220Ω resistor**.
     - **Ring (R)**: Connect to **GND**.
     - **Sleeve (S)**: Connect to **GND** (shield connection).
     - **Protection Diode**:
       - Add a **Schottky diode (1N5819)** between **Tip** (output) and **GND** with the cathode connected to **Tip** to provide reverse current protection.

5. **Power Supply and Decoupling**:

   - Connect **+5V** and **GND** to the **74HC14** IC.
   - Place a **0.1µF decoupling capacitor** close to the power supply pins of the IC to filter out high-frequency noise.

#### **Summary of Connections**

- The **TX from Serial3** is connected to the **LED side** of the **6N137 optocoupler** through a **220Ω resistor**.
- The **output side of the 6N137** provides an isolated signal that is pulled up to **+5V** with a **4.7kΩ resistor**.
- The isolated signal is then **buffered** using a **74HC14**, which fans out the signal to the four separate MIDI outputs.
- **MIDI OUT 1 and 2** use **DIN jacks**, while **MIDI OUT 3 and 4** use **TRS jacks** for compatibility with devices that use TRS MIDI connections.
- Each **MIDI output** is connected through a **220Ω resistor**, and **Schottky diodes** are used for protection.

#### **Benefits of This Design**

- **Isolation**: The use of the **6N137** ensures that the Arduino MEGA is electrically isolated from the MIDI outputs, protecting it from any harmful electrical spikes.
- **Signal Integrity**: The **buffer IC** provides strong signal drive capability, ensuring all four MIDI outputs have consistent signal levels without degradation.
- **Protection**: **Schottky diodes** and **current-limiting resistors** safeguard the output against overcurrent and reverse polarity.

This design will provide a reliable way to multiply the **Serial3** output into four MIDI outputs while maintaining signal integrity and protecting both the Arduino and connected MIDI devices.

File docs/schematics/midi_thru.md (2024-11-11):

### MIDI Thru Schematics Review

#### **Review of the MIDI Thru Schematics**:

1. **Current Configuration**:
   - The **MIDI Thru circuits (J3, J4)** are well-configured to pass through the MIDI signal from the inputs (TX Serial1 and TX Serial2) directly to the MIDI Thru ports.
   - The **220Ω resistors (R5, R6)** are correctly used to limit the current on the MIDI lines. This is in accordance with the MIDI specification to ensure reliable signal transmission while avoiding excessive current draw.

2. **Diode Protection**:
   - **Schottky diodes (D5, D6)** are used to protect the output lines. These diodes clamp any reverse voltage or spikes, thereby protecting the output stage from potential damage. This is good practice for ensuring that unexpected signals do not cause harm.

3. **Power Supply Considerations**:
   - The **5V power supply** is routed through the **220Ω resistors** to the MIDI Thru output pins, which ensures proper signal levels while limiting current as per the MIDI standards.

#### **Suggestions for Improvement**:

1. **Capacitor Addition**:
   - Adding a small **capacitor (10pF to 22pF)** across the output lines could help filter out any high-frequency noise. This will be particularly useful if there is a significant amount of electromagnetic interference (EMI) in the environment, thereby ensuring cleaner output signals.

2. **PCB Layout**:
   - Keep the **ground connections** short and direct to minimize noise. A solid **ground plane** under the MIDI Thru section would be beneficial to further minimize EMI and ensure signal stability.

#### **Summary**:

The MIDI Thru schematics are solid, with a good balance of signal integrity and protection. The use of **Schottky diodes** and **current-limiting resistors** aligns well with industry practices for MIDI circuits. Adding small filtering capacitors across the output lines could further improve noise suppression and overall stability.

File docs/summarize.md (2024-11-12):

### 1. **Main Ideas and Initial Concepts**
   - The core idea is to build a MIDI merge device that merges MIDI data from two inputs and outputs through multiple channels. This device also manages a clock signal, providing precise timing and synchronization to connected MIDI equipment.
   - Key features include:
     - **Master Clock Selection**: An SPDT switch allows for selecting the master MIDI clock source.
     - **Analog Clock Output**: Synchronized with the MIDI clock for external device control.
     - **Adjustable Clock Pulse Resolution**: Allows for user control over the clock pulse-per-quarter note (PPQN).
     - **OLED Display**: Displays BPM, clock rate, and other useful information.
   - The **Arduino MEGA 2560 Pro** is used as the primary microcontroller for its multiple I/O pins and capability to handle complex MIDI merging tasks.

### 2. **MIDI Circuitry and Clock Management**
   - **MIDI Input Circuit**: The design incorporates optocouplers (6N137) for proper isolation, ensuring safe handling of incoming MIDI signals without electrical interference.
   - **MIDI Thru and Output Circuits**: Designed to accurately route MIDI signals from the Arduino to multiple MIDI outputs while ensuring protection through the use of resistors and diodes.
   - **Clock Signal Shaping**: Implemented using the 74HC14 Schmitt Trigger IC to clean up the clock pulses, thereby eliminating noise and providing a stable MIDI clock output.

### 3. **Design Considerations for Protection and Filtering**
   - **Surge and Reverse Polarity Protection**: 1N5819 Schottky diodes were added to protect the power inputs and MIDI signal lines from voltage surges and reverse polarity.
   - **Filtering Capacitors**: Various capacitors were incorporated in critical areas of the circuit:
     - **Clock Output Filtering**: Added to stabilize the clock signal for connected MIDI devices.
     - **Power Line Filtering**: Used to reduce noise and maintain stability near sensitive components like optocouplers.
   - **Pull-Up and Pull-Down Resistors**: Selected to maintain correct voltage levels for signal detection and to stabilize the digital lines.

### 4. **Code and Software Development**
   - **Clock Signal Generation**: Initially, PWM was considered for generating the clock pulses; however, it was recognized that using **Timer1** would provide more precise and consistent timing, addressing the inaccuracies inherent in PWM.
   - **MIDI Input Handling**: The code was structured to receive MIDI messages in **MIDI_CHANNEL_OMNI** mode, allowing the device to respond to any channel.
   - **Set Handle Message Method**: A method was included for handling incoming MIDI messages effectively. We also discussed the possibility of detaching or optimizing this function to improve code modularity.

### 5. **Recent Improvements and Iterations**
   - **Clock Output Circuit Update**: Recently, capacitors (C14, C15) were added to the clock output stage for further noise filtering, ensuring that the clock output is stable and clean.
   - **Component Value Review**: Detailed reviews of resistor and capacitor values were conducted, focusing on ensuring that timing and pulse characteristics meet the requirements of the MIDI specification.
   - **Decoupling Capacitors**: It was suggested to add decoupling capacitors near the 74HC14 IC to minimize the impact of power line noise, which could interfere with pulse stability.

### 6. **Project Progress and Future Considerations**
   - **Progress Overview**:
     - The hardware components, including input and output circuits, power protection, clock signal conditioning, and user interface, have been prototyped and tested.
     - Software functionality for merging MIDI inputs, controlling clock output, and handling MIDI messages is well underway, with a focus on improving timing precision.
   - **Upcoming Improvements**:
     - Implementing **Timer1** for clock generation to replace PWM and improve clock signal accuracy.
     - Testing the RC filter networks to ensure no unintended delays or signal issues affect the precision of the MIDI clock output.
     - Modularizing the code for better readability and maintenance, potentially splitting the MIDI handling, clock generation, and display functions into separate, reusable modules.

Overall, the project has transformed from an initial concept into a sophisticated MIDI merging and clock management device. The integration of effective isolation, filtering, and protection measures—along with clean clock signal generation—has ensured reliable operation and precise MIDI timing. Moving forward, the focus will be on refining timing accuracy, enhancing modularity in the code, and finalizing the design for stability and usability in practical scenarios.

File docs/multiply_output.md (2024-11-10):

If you want to **multiply the MIDI output to 4 outputs**, you can use an **Active MIDI Thru circuit**. Below, I'll walk you through how you can design and implement a circuit that takes one MIDI output signal and splits it into **four independent outputs**, each capable of driving a separate MIDI device.

### **Components Required**:
- **1x 6N138 Optocoupler** or compatible opto-isolator
- **1x 74HC14 Hex Schmitt Trigger Inverter** IC
- **4x 220Ω Resistors** (current limiting for MIDI outputs)
- **4x MIDI DIN 5-pin Connectors** (for MIDI output)
- **1x 1kΩ Resistor** (current limiting for optocoupler input)
- **1x 10kΩ Resistor** (pull-up for optocoupler output)
- **1x 5V Power Supply** (can be sourced from the microcontroller or an external supply)

### **Circuit Design Overview**:

1. **MIDI Input Section**:
   - The signal from the `MIDIOUT` pin of your microcontroller is connected to the **6N138 optocoupler**.
   - The **anode** (pin 2) of the optocoupler is connected to **+5V** through a **1kΩ resistor**.
   - The **cathode** (pin 3) is connected to the `MIDIOUT` line and **GND**.
   - The output of the **6N138** is taken from **pin 6** and connected to the **input of the 74HC14** (through a **10kΩ pull-up resistor** to 5V).

2. **Buffer Stage (74HC14 IC)**:
   - The **74HC14** is a hex inverter with Schmitt Trigger inputs, which ensures clean signal transitions.
   - The **output** from the **6N138 optocoupler** (pin 6) is connected to the **input of one inverter** on the **74HC14** (e.g., **pin 1**).
   - The **output of that inverter** (e.g., **pin 2**) is then used as the main MIDI output signal.
   - Use the remaining **four inverters** on the **74HC14** to create **four identical MIDI output signals**.

3. **Output Stage**:
   - Each output from the **74HC14** is connected to a **MIDI DIN connector** through a **220Ω resistor**.
   - The resistor limits the current to comply with MIDI standards.
   - Connect **pin 5** of each **MIDI DIN connector** to **+5V** through another **220Ω resistor**.
   - **Pin 2** of each **MIDI DIN connector** should be connected to **GND**.

### **Detailed Wiring**:
1. **Input Section with Optocoupler**:
   - **Pin 2 (Anode) of 6N138**: Connected to **+5V** via a **1kΩ resistor**.
   - **Pin 3 (Cathode) of 6N138**: Connected to `MIDIOUT` line from your microcontroller.
   - **Pin 5** (Collector output) is grounded.
   - **Pin 6 (Emitter output)**: Connected to the input of the **74HC14** and a **10kΩ pull-up resistor** to **+5V**.

2. **Buffering with 74HC14 Hex Schmitt Trigger**:
   - **Pin 1 (Input)**: Connected to the output of the **6N138**.
   - **Pin 2 (Output)**: Buffered **MIDI signal**.
   - The output of **pin 2** is connected to the **inputs** of four other inverters (**pins 3, 5, 9, 11**) on the **74HC14**.
   - Each output from these inverters (**pins 4, 6, 8, 10**) is then used to drive separate MIDI outputs.

3. **MIDI Output Stage**:
   - Each **output pin** from the **74HC14** goes through a **220Ω resistor** and is connected to **pin 4** of the **MIDI DIN connector**.
   - **Pin 5** of each **MIDI DIN connector** should also have a **220Ω resistor** connected to **+5V**.
   - **Pin 2** of each **MIDI DIN connector** is connected to **GND**.

### **MIDI Connector Pinout**:
- **Pin 2**: **GND**
- **Pin 4**: **MIDI Signal Out** (comes from **74HC14** via a **220Ω resistor**)
- **Pin 5**: Connected to **+5V** through a **220Ω resistor**.

### **Explanation**:
- The **6N138 optocoupler** is used to isolate the original MIDI signal.
- The **74HC14** is used to buffer and split the MIDI signal into multiple outputs.
- Each output has its own **220Ω resistor** to comply with the MIDI electrical specifications.
- The result is **four identical MIDI outputs** capable of driving multiple devices while preserving signal integrity.

### **Diagram Summary**:
1. **Input Stage**:
   - `MIDIOUT` -> 6N138 -> **74HC14 Pin 1** (Buffered).
2. **Output Stage** (using 74HC14):
   - **Pin 2** of the 74HC14 drives **MIDI OUT1**.
   - **Pins 4, 6, 8, 10** drive **MIDI OUT2, OUT3, OUT4** respectively.

This design gives you **four identical MIDI outputs** that you can connect to different devices, ensuring that all receive the same MIDI data without compromising signal quality. This approach is widely used in **MIDI Thru** boxes.

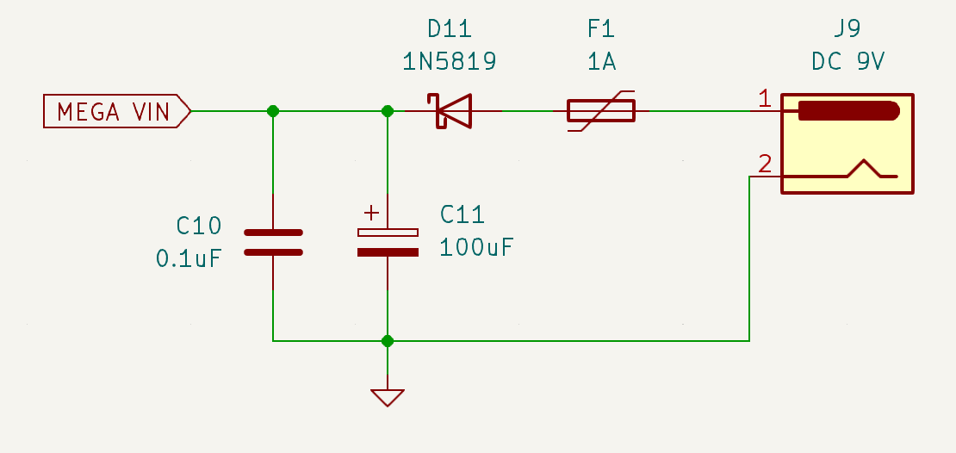
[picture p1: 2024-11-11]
docs/schematics/dc_jack.png

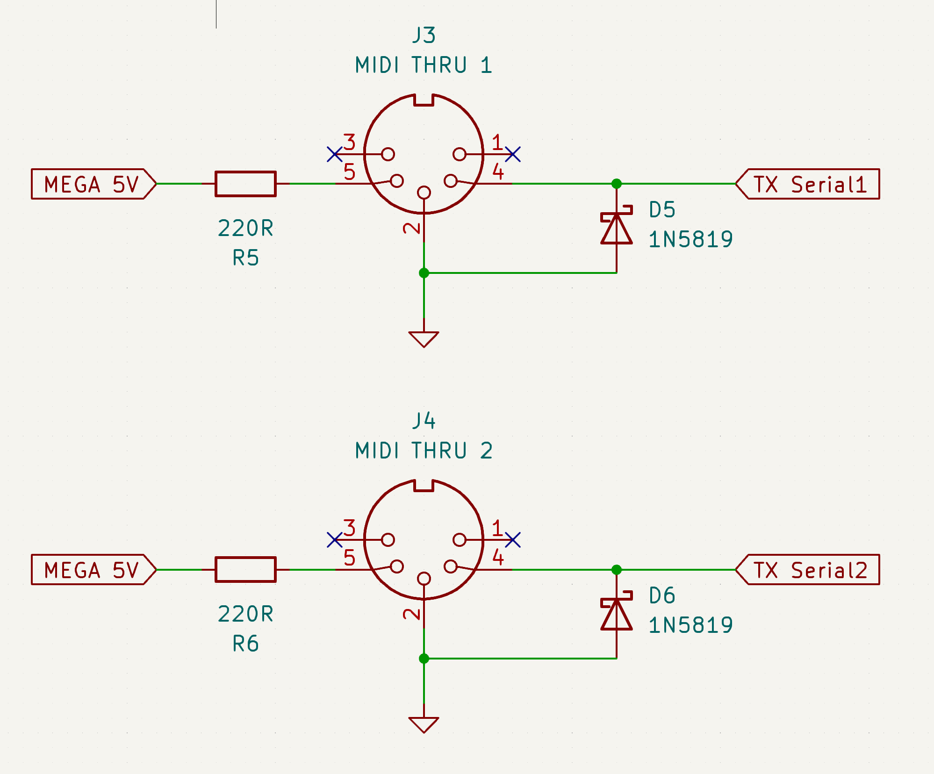
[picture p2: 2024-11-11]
docs/schematics/midi_thru.png

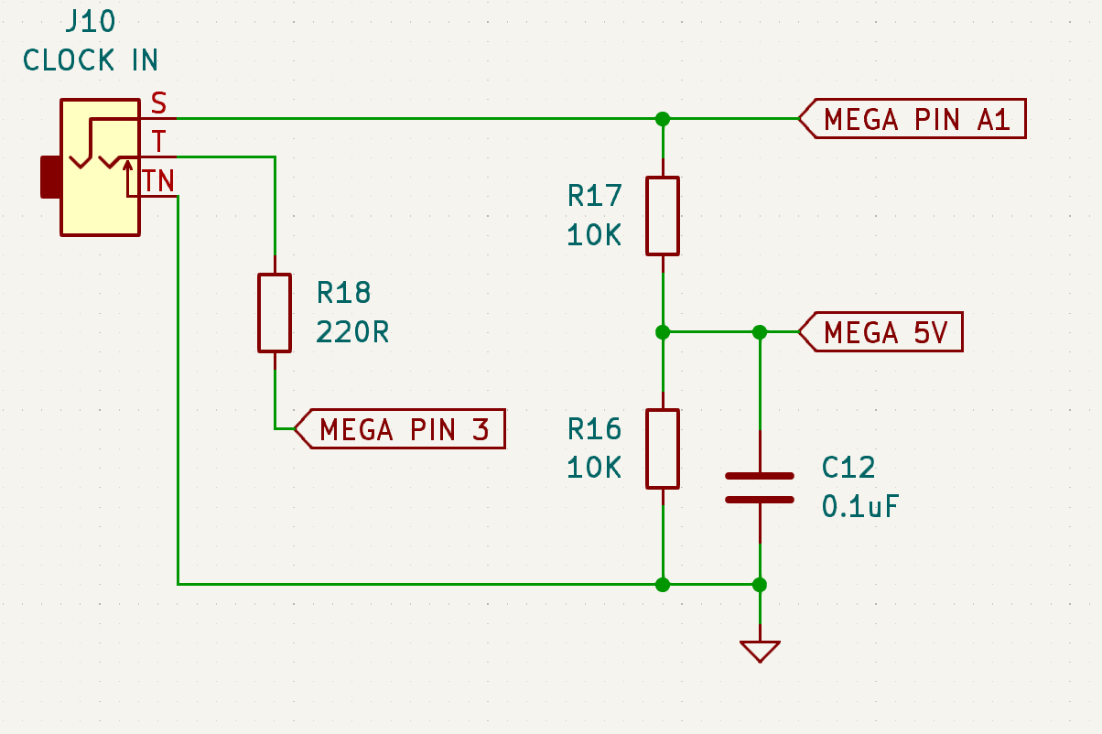
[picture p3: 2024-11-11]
docs/schematics/clock_in.png

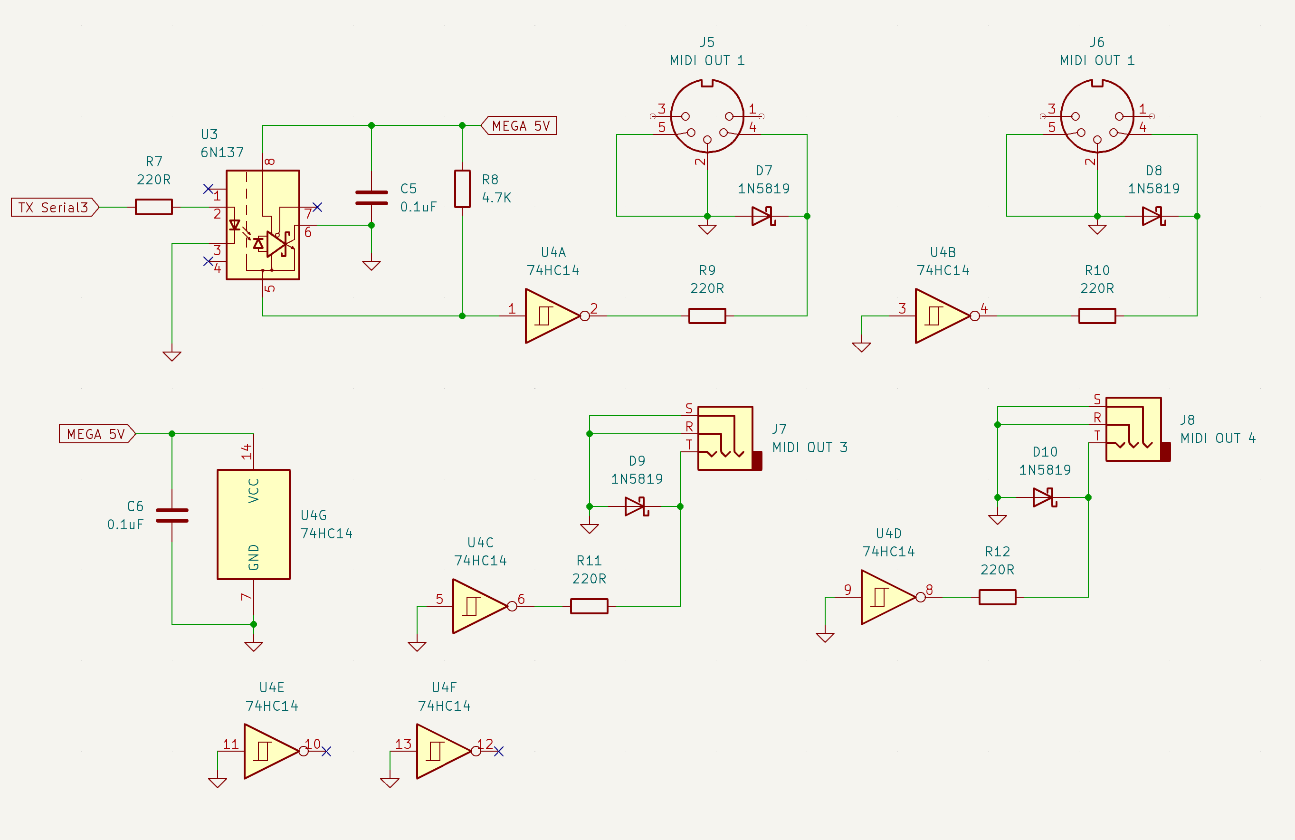
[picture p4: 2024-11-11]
docs/schematics/midi_out_multiply.png

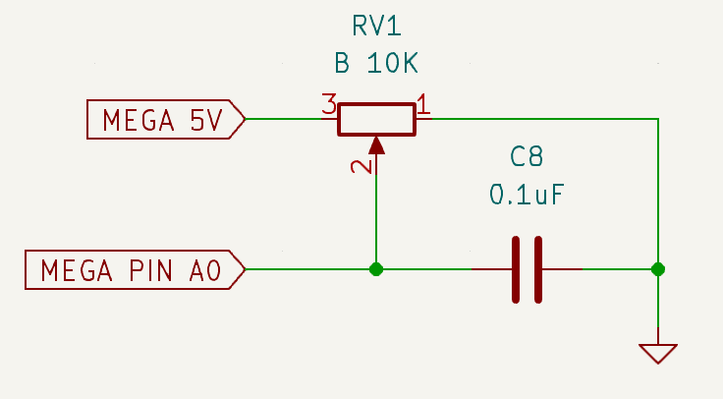
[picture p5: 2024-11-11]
docs/schematics/clock_rate.png

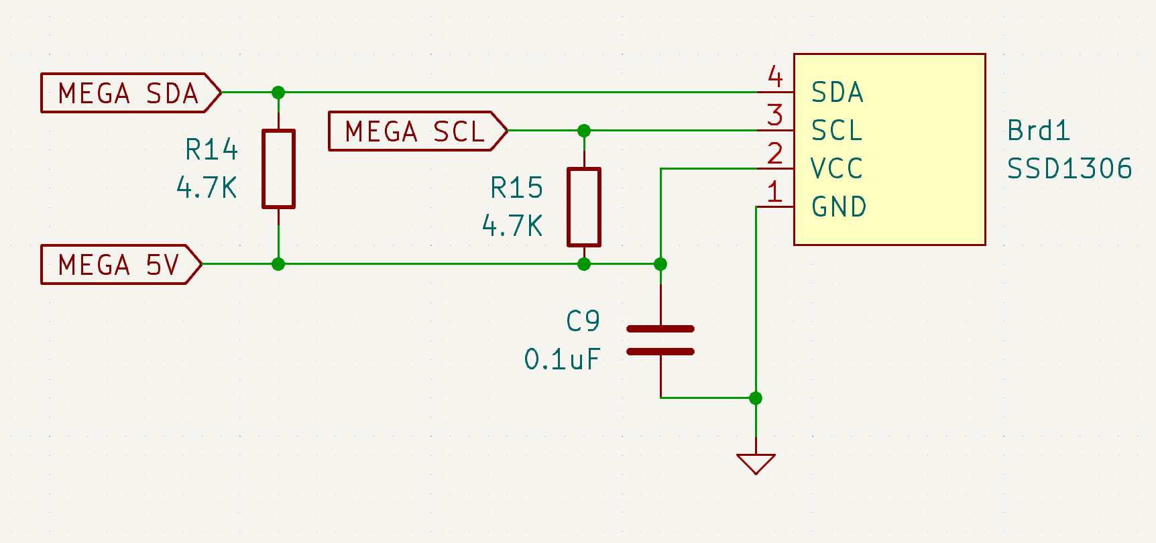
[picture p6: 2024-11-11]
docs/schematics/display_oled.png

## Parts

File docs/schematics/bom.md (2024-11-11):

**Complete Bill of Materials (BOM) for MIDI Merge Device**

| **Component** | **Value** | **Quantity** |
|---|---|---|
| Microcontroller |MEGA 2560 Pro | 1 |
| Resistor	| 220R	| 13 |
| Diode	| 1N5819	| 9 |
| DIN-5 MIDI Connector	| -	| 6 |
| Diode	| 5.1V Zener	| 2 |
| Capacitor	| 10pF	| 2 |
| IC	| 6N137 Optocoupler	| 3 |
| Resistor	| 4.7K	| 5 |
| Capacitor	| 0.1µF	| 8 |
| IC	| 74HC14 Schmitt Trigger Inverter	| 1 |
| TRS Jack	| 3.5mm	| 2 |
| SPDT Switch	| -	| 1 |
| Capacitor	| 10nF	| 1 |
| Resistor	| 10K	| 5 |
| OLED	| SSD1306 128x32	| 1 |
| DC Jack	| 9V	| 1 |
| Polyfuse	| 3A	| 1 |
| Capacitor	| 100uF Electrolyte	| 1 |
| Potentiometer	| 10K B Linear	| 1 |
| Capacitor	| 1uF	| 1 |
| TS Jack	| 3.5mm	| 3 |
| Enclosure	| 100x150mm	| 1 |

UPDATED: https://docs.google.com/spreadsheets/d/1cj7JBLucuG0cxtF-Ae_7uXMHBq7VAGNTWUeZMDdKlCk/edit?gid=0#gid=0

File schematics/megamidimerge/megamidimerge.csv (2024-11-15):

# | Reference | Qty | Value | Footprint | DNP
1 | Brd1 | 1 | SSD1306
2 | C1, C3 | 2 | 10pF | Capacitor_THT:C_Rect_L7.2mm_W2.5mm_P5.00mm_FKS2_FKP2_MKS2_MKP2
3 | C2, C4, C5, C6, C8, C9, C10, C12 | 8 | 0.1uF | Capacitor_THT:C_Rect_L7.2mm_W2.5mm_P5.00mm_FKS2_FKP2_MKS2_MKP2
4 | C7 | 1 | 10nF | Capacitor_THT:C_Rect_L7.2mm_W2.5mm_P5.00mm_FKS2_FKP2_MKS2_MKP2
5 | C11 | 1 | 100uF
6 | C13 | 1 | 1uF | Capacitor_THT:C_Rect_L7.2mm_W2.5mm_P5.00mm_FKS2_FKP2_MKS2_MKP2
7 | D1, D3 | 2 | 5.1V | Diode_THT:D_DO-35_SOD27_P7.62mm_Horizontal
8 | D2, D4, D5, D6, D7, D8, D9, D10, D11 | 9 | 1N5819 | Diode_THT:D_DO-41_SOD81_P10.16mm_Horizontal
9 | F1 | 1 | 1A
10 | J1 | 1 | MIDI IN 1
11 | J2 | 1 | MIDI IN 2
12 | J3 | 1 | MIDI THRU 1
13 | J4 | 1 | MIDI THRU 2
14 | J5, J6 | 2 | MIDI OUT 1
15 | J7 | 1 | MIDI OUT 3
16 | J8 | 1 | MIDI OUT 4
17 | J9 | 1 | DC 9V
18 | J10 | 1 | CLOCK IN
19 | J11 | 1 | CLOCK OUT 1
20 | J12 | 1 | CLOCK OUT 2
21 | R1, R3, R5, R6, R7, R9, R10, R11, R12, R18, R21, R22 | 12 | 220R | Resistor_THT:R_Axial_DIN0207_L6.3mm_D2.5mm_P10.16mm_Horizontal
22 | R2, R4, R8, R14, R15 | 5 | 4.7K | Resistor_THT:R_Axial_DIN0207_L6.3mm_D2.5mm_P10.16mm_Horizontal
23 | R13, R16, R17, R19, R20 | 5 | 10K | Resistor_THT:R_Axial_DIN0207_L6.3mm_D2.5mm_P10.16mm_Horizontal
24 | RV1 | 1 | B 10K
25 | SW1 | 1 | MASTER CLOCK
26 | U1, U2, U3 | 3 | 6N137 | Package_DIP:DIP-8_W7.62mm
27 | U4 | 1 | 74HC14

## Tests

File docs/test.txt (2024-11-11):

My main goal is to create a MIDI merge device which have functionality:
1. Core Function: Merges MIDI data from two MIDI inputs and sends it a MIDI output
2. Master Clock Selection: An SPDT switch allows you to choose which MIDI input provides the master clock
3. Analog Clock Output: Generates an analog clock signal synchronized with the MIDI clock
4. Clock Pulse Rate: A knob to control the clock pulse per quarter note (1 to 24 ppqn) for the analog clock output
5. Active Master Clock Display: Shows the active MIDI Input acting as the Master Clock on an OLED display
6. BPM Display: Displays the Beats Per Minute (BPM) in 4/4 time signature based on selected master clock
7. Clock Rate Display: based on the selected resolution setting
8. Analog Clock Input: Override MIDI master clock

Device Specifications:
1. MEGA 2560 Pro
2. 2 MIDI Input
3. 2 MIDI Thru (corresponding from MIDI input)
4. 4 MIDI Out (each transmitting MIDI Messages merged from both MIDI Input)
5. 1 Toggle switch to choose Master Clock
6. 1 Clock Output
7. 1 Clock Input
8. 1 128x32 OLED Display
9. 1 DC Power Connector

I've already have a working prototype and codes but I'd like an improvements.
I'll show you the code on canvas.

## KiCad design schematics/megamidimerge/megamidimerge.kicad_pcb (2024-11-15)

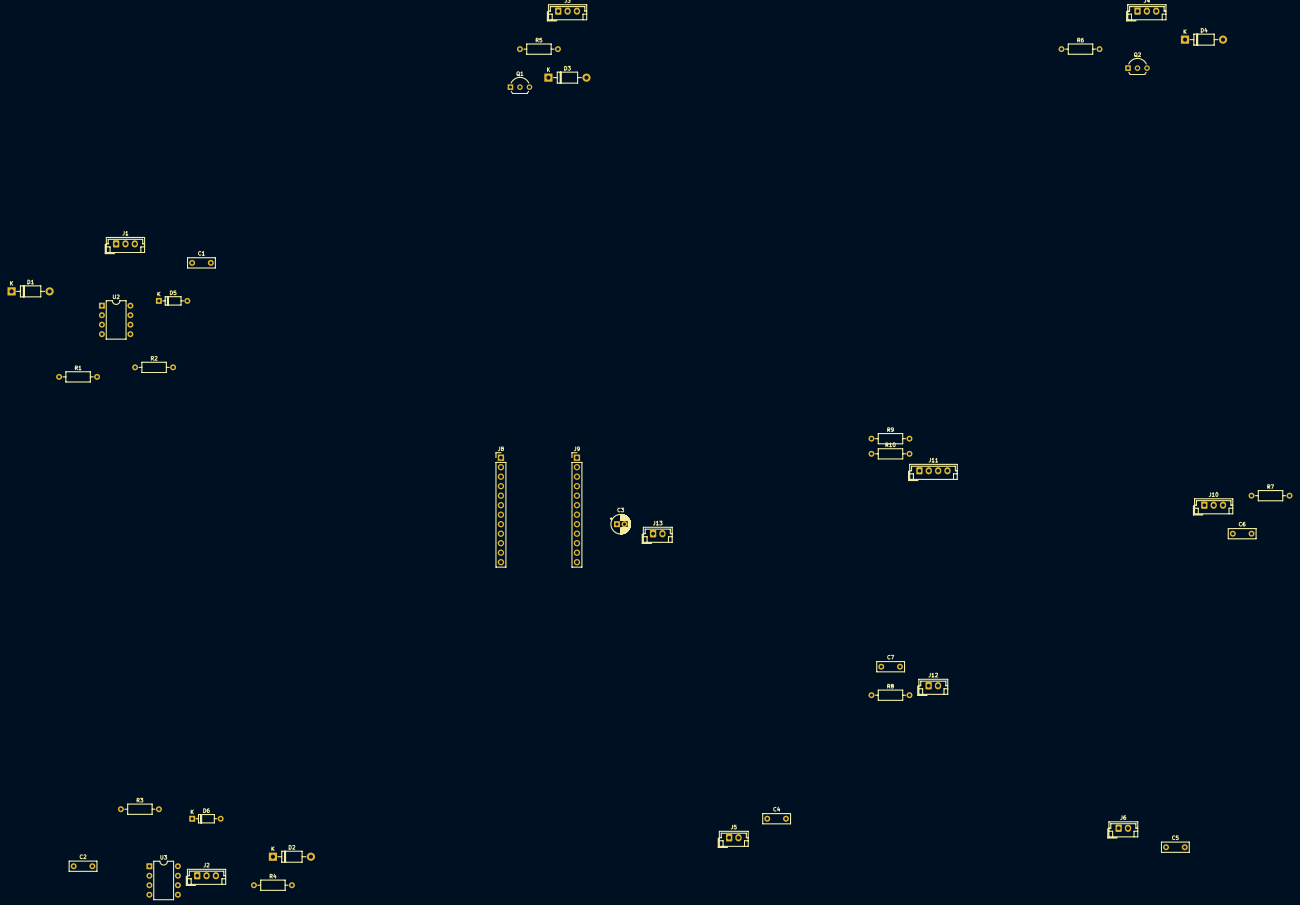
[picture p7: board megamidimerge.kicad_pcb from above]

Board: 2 copper layers, 39 parts (0 on the bottom side), 24 nets, no tracks yet.

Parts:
C1, C2: 0.1uF; C_Rect_L7.2mm_W2.5mm_P5.00mm_FKS2_FKP2_MKS2_MKP2
C3: 10uF; CP_Radial_D5.0mm_P2.00mm
C4, C5, C6, C7: 10nF; C_Rect_L7.2mm_W2.5mm_P5.00mm_FKS2_FKP2_MKS2_MKP2
D1, D2, D3, D4: 1N5819; D_DO-41_SOD81_P10.16mm_Horizontal
D5, D6: 5.1V; D_DO-35_SOD27_P7.62mm_Horizontal
J1: MIDI IN 1; JST_EH_B3B-EH-A_1x03_P2.50mm_Vertical
J2: MIDI IN 2; JST_EH_B3B-EH-A_1x03_P2.50mm_Vertical
J3: MIDI OUT 1; JST_EH_B3B-EH-A_1x03_P2.50mm_Vertical
J4: MIDI OUT 2; JST_EH_B3B-EH-A_1x03_P2.50mm_Vertical
J5: CLOCK OUT 1; JST_EH_B2B-EH-A_1x02_P2.50mm_Vertical
J6: CLOCK OUT 2; JST_EH_B2B-EH-A_1x02_P2.50mm_Vertical
J8: LEFT; PinHeader_1x12_P2.54mm_Vertical
J9: RIGHT; PinHeader_1x12_P2.54mm_Vertical
J10: SWITCH MASTER; JST_EH_B3B-EH-A_1x03_P2.50mm_Vertical
J11: LCD; JST_EH_B4B-EH-A_1x04_P2.50mm_Vertical
J12: RESOLUTION; JST_EH_B2B-EH-A_1x02_P2.50mm_Vertical
J13: DC; JST_EH_B2B-EH-A_1x02_P2.50mm_Vertical
Q1, Q2: 2N2222; TO-92L_Inline_Wide
R1, R3, R5, R6: 220R; R_Axial_DIN0207_L6.3mm_D2.5mm_P10.16mm_Horizontal
R2, R4, R9, R10: 4.7K; R_Axial_DIN0207_L6.3mm_D2.5mm_P10.16mm_Horizontal
R7, R8: 10K; R_Axial_DIN0207_L6.3mm_D2.5mm_P10.16mm_Horizontal
U2, U3: 6N137; DIP-8_W7.62mm

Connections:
CLK1: C4.2, J5.2, J8.9
CLK2: C5.2, J6.2, J8.11
CPR: C7.1, J8.8, J12.1, R8.2
CSW: C6.1, J8.7, J10.2, R7.2
GND: C1.2, C2.2, C3.2, C4.1, C5.1, C6.2, C7.2, D3.2 (A), D4.2 (A), J1.3, J2.3, J3.3, J4.3, J5.1, J6.1, J8.3, J8.4, J9.2, J10.3, J11.1, J12.2, J13.2, Q1.3 (E), Q2.3 (E), R7.1, R8.1, U2.5 (GND), U3.5 (GND)
IN1: J8.2, R2.1, U2.6 (VO)
IN2: J8.10, R4.1, U3.6 (VO)
unnamed: D1.2 (A), J1.2, U2.3 (C)
unnamed: D1.1 (K), R1.2, U2.2 (A)
unnamed: D2.2 (A), J2.2, U3.3 (C)
unnamed: D2.1 (K), R3.2, U3.2 (A)
unnamed: D3.1 (K), J3.2, Q1.1 (C)
unnamed: D4.1 (K), J4.2, Q2.1 (C)
unnamed: D5.2 (A), J1.1
unnamed: D5.1 (K), R1.1
unnamed: D6.2 (A), J2.1
unnamed: D6.1 (K), R3.1
unnamed: Q1.2 (B), R5.2
unnamed: Q2.2 (B), R6.2
OUT1: J8.1, R5.1
OUT2: J9.9, R6.1
SCL: J8.6, J11.3, R10.2
SDA: J8.5, J11.4, R9.2
VCC: C1.1, C2.1, C3.1, J3.1, J4.1, J9.4, J10.1, J11.2, J13.1, R2.2, R4.2, R9.1, R10.1, U2.8 (VCC), U3.8 (VCC)

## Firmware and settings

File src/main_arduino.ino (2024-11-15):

#include <Wire.h>
#include <Adafruit_GFX.h>
#include <Adafruit_SSD1306.h>
#include <MIDI.h>  // Include the MIDI library

#define VERSION "v0.0.1"

// OLED display settings
#define SCREEN_WIDTH 128
#define SCREEN_HEIGHT 32
#define OLED_I2C_ADDRESS 0x3C
//OLED PIN IN MEGA ARE:
//  SDA PIN 20
//  SCL PIN 21

#define MASTER_SWITCH_PIN 7
#define CLOCK_OUT_PIN 8  // Clock Output using Digital Pin
#define RESOLUTION_KNOB_PIN A0   //PIN 54       // Analog input pin for Clock Pulse Rate knob
#define CLOCK_IN_PIN 2                   // Clock Input using Digital Pin
#define CLOCK_IN_PLUG_DETECT_PIN A1  //PIN 55     // Pin to detect if Clock In is plugged in

// Bonus: Gameboy sync
#define GB_CLOCK_PIN PIN_PA0    // pin 22 PORTA0
#define GB_SI_PIN PIN_PA1       // pin 23 PORTA1 // to Gameboy Serial Out
#define GB_SO_PIN PIN_PA2       // pin 24 PORTA2 // to Gameboy Serial In


Adafruit_SSD1306 display(SCREEN_WIDTH, SCREEN_HEIGHT, &Wire, -1);

// MIDI instance for using Serial1, Serial2, and Serial3 as MIDI ports
MIDI_CREATE_INSTANCE(HardwareSerial, Serial1, MIDIINPUT1); // Use Hardware UART1 - OUT TX PIN 18, IN RX PIN 19
MIDI_CREATE_INSTANCE(HardwareSerial, Serial2, MIDIINPUT2); // Use Hardware UART2 - OUT TX PIN 16, IN RX PIN 17
MIDI_CREATE_INSTANCE(HardwareSerial, Serial3, MIDIOUTPUT); // Use Hardware UART3 - OUT TX PIN 14, NC RX PIN 15 (NC = Not Connected to Ground)

// Variables for BPM
unsigned long clockCount = 0;   // Count of MIDI Clock messages
unsigned long lastBPMTime = 0;            // Last time BPM was calculated
unsigned int bpm = 0;                     // Calculated BPM as an integer
const int numerator = 4;                   // Fixed numerator for 4/4 (quarter note)
int clockPulseCount = 0;          // Count of MIDI Clock pulses for analog clock
const int ppqn = 24;                    // Pulses Per Quarter Note
unsigned int resolution = 6;                     // Clock Resolution
unsigned long lastPulseTime = 0;            // Last time Pulse was calculated (HIGH)
volatile bool clockInputPulse = false; // Modified within ISR, so 'volatile' is necessary       // Flag for detecting clock input pulses
const int clockPulseInterval = 5;

bool isMasterInput1() {
    return digitalRead(MASTER_SWITCH_PIN) == HIGH;
}

bool isClockInPlugged() {
    return analogRead(CLOCK_IN_PLUG_DETECT_PIN) < 100;  // Plug is inserted threshbold input less than 100
}

void printDisplay() {
    display.clearDisplay();
    display.setCursor(0, 0);
    display.print("MEGAMIDI MERGE");
    display.setCursor(0, 10);
    display.print(isClockInPlugged() ? "Clock In BPM: " : (isMasterInput1() ? "MIDI [1] BPM: " : "MIDI [2] BPM: "));
    display.print(bpm);
    display.setCursor(0, 20);
    display.print("Clock Rate: ");
    display.print(resolution);
    String measure;
    switch (resolution) {
        case 24: measure = " [1/4]"; break;
        case 16: measure = " [1/4T]"; break;
        case 12: measure = " [1/8]"; break;
        case 8: measure = " [1/8T]"; break;
        case 6: measure = " [1/16]"; break;
        case 4: measure = " [1/16T]"; break;
        case 3: measure = " [1/32]"; break;
        case 2: measure = " [1/32T]"; break;
        case 1: measure = " [1/64]"; break;
        default: measure = " N/A"; break;
    }
    display.print(measure);
    display.display();
}

void calculateBPM() {
  // Calculate BPM based on the number of clock messages received
  bpm = (clockCount * 60 * 4) / (ppqn * numerator); // Adjust BPM based on fixed numerator using integer arithmetic
  clockCount = 0; // Reset the clock count after calculation
}

// Update BPM every second
void handleDisplay() {
  unsigned long currentTime = millis();
  if (currentTime - lastBPMTime >= 1000) { // Calculate BPM every second
      calculateBPM();
      lastBPMTime = currentTime;
      printDisplay();
  }
}

// Handle MIDI Clock and timing-related messages with precise forwarding
void sendRealTimeMessage(byte messageType) {
  switch (messageType) {
        case midi::Clock:
            clockCount++; // BPM Counting clock
            MIDIOUTPUT.sendRealTime(midi::Clock);
            generateDigitalClockPulse(); // Generate digital clock pulse
            sendClockPulseToLSDJ(); // send to GameBoy slave sync mode: MIDI
            break;
        case midi::Start:
            MIDIOUTPUT.sendRealTime(midi::Start);
            break;
        case midi::Continue:
            MIDIOUTPUT.sendRealTime(midi::Continue);
            break;
        case midi::Stop:
            MIDIOUTPUT.sendRealTime(midi::Stop);
            break;
        case midi::ActiveSensing:
            MIDIOUTPUT.sendRealTime(midi::ActiveSensing);
            break;
        case midi::SystemReset:
            MIDIOUTPUT.sendRealTime(midi::SystemReset);
            break;
        default:
            // Handle other message types if necessary
            break;
  }
}

// Function to forward a MIDI message to a given MIDI output
template <typename T>
void forwardMessage(midi::MidiInterface<T> &midiInput, const midi::Message<128>& message) {
    byte messageType = message.type;

    // Filter out clock and timing-related messages if not from the master
    if (messageType == midi::Clock || messageType == midi::Start || messageType == midi::Continue || messageType == midi::Stop || messageType == midi::ActiveSensing) {
        if (!isClockInPlugged()) {
          bool isMasterInput1Active = isMasterInput1();
          bool isMidiInput1 = (&midiInput == &MIDIINPUT1);
          bool isMidiInput2 = (&midiInput == &MIDIINPUT2);
          if ((isMasterInput1Active && isMidiInput1) || (!isMasterInput1Active && isMidiInput2)) {
            sendRealTimeMessage(messageType);
          }
        }
        return; // Do not forward these messages
    }

    byte channel = message.channel;
    byte data1 = message.data1;
    byte data2 = message.data2;
    
    switch (messageType) {
        case midi::NoteOn:
            MIDIOUTPUT.sendNoteOn(data1, data2, channel);
            break;
        case midi::NoteOff:
            MIDIOUTPUT.sendNoteOff(data1, data2, channel);
            break;
        case midi::ProgramChange:
            MIDIOUTPUT.sendProgramChange(data1, channel);
            break;
        case midi::ControlChange:
            MIDIOUTPUT.sendControlChange(data1, data2, channel);
            break;
        case midi::PitchBend:
            MIDIOUTPUT.sendPitchBend((data2 << 7) | data1, channel);
            break;
        case midi::AfterTouchPoly:
            MIDIOUTPUT.sendAfterTouch(data1, data2, channel);
            break;
        case midi::AfterTouchChannel:
            MIDIOUTPUT.sendAfterTouch(data1, channel);
            break;
        case midi::TimeCodeQuarterFrame:
            MIDIOUTPUT.sendTimeCodeQuarterFrame(data1);
            break;
        case midi::SongPosition:
            MIDIOUTPUT.sendSongPosition((data2 << 7) | data1);
            break;
        case midi::SongSelect:
            MIDIOUTPUT.sendSongSelect(data1);
            break;
        case midi::TuneRequest:
            MIDIOUTPUT.sendTuneRequest();
            break;
        default:
            // Handle other message types if necessary
            break;
    }
}

// Generate digital clock pulse on additional digital pin
void generateDigitalClockPulse() {
    clockPulseCount++;
    unsigned long currentTime = millis();
    if (clockPulseCount >= resolution) { // Generate a pulse based on resolution
        clockPulseCount = 0;
        digitalWrite(CLOCK_OUT_PIN, HIGH);
        lastPulseTime = currentTime;
    }
}

// Generate digital clock pulse to gameboy
// Using macro to PORTS
// based Arduinoboy https://github.com/trash80/Arduinoboy/blob/master/Arduinoboy/Mode_LSDJ_SlaveSync.ino
// Thanks to @trash80
void sendClockPulseToLSDJ() {
  for(int ticks = 0; ticks < 8; ticks++) {
    digitalWrite(GB_CLOCK_PIN, LOW);
    digitalWrite(GB_CLOCK_PIN, HIGH);
  }
}

void handleClockOut() {
  unsigned long currentTime = millis();
  if (currentTime - lastPulseTime >= clockPulseInterval) { //5 millisecond non delay pulse out
    digitalWrite(CLOCK_OUT_PIN, LOW);
  }

  // Read RESOLUTION knob value and map it to predefined RESOLUTION values
  int knobValue = analogRead(RESOLUTION_KNOB_PIN);
  const int snappedValues[] = {24, 16, 12, 8, 6, 4, 3, 2, 1, 0};
  int index = map(knobValue, 0, 1023, 0, 9); // Map knob value to index 9, ensures that when knobValue is close to the maximum (1023), the index can reach 8.
  index = constrain(index, 0, 8);   // Ensure index stays within the range 0-8
  resolution = snappedValues[index];
}

// Clock Input Interrupt Service Routine (ISR)
void clockInISR() {
    clockInputPulse = true; // Set clock input flag when a pulse is detected
}

void handleClockIn() {
  if (isClockInPlugged() && clockInputPulse) {
    sendRealTimeMessage(midi::Clock); //override MIDI Clock
    clockInputPulse = false;
  }
}

// Generic MIDI Message handler to forward all MIDI1 messages to MIDI2 and MIDI3
void forwardMessageInput1(const midi::Message<128>& message) {
    forwardMessage(MIDIINPUT1, message);
}

// Generic MIDI Message handler to forward all MIDI2 messages to MIDI1 and MIDI3
void forwardMessageInput2(const midi::Message<128>& message) {
    forwardMessage(MIDIINPUT2, message);
}

void setup() {
    pinMode(MASTER_SWITCH_PIN, INPUT_PULLUP); // Set CSW_PIN as input for the SPDT master clock switch (non-serial, non-I2C)
    pinMode(CLOCK_OUT_PIN, OUTPUT); // Set CLOCK_OUT_DIGITAL_PIN as output for digital clock
    pinMode(RESOLUTION_KNOB_PIN, INPUT); // Set RESOLUTION_KNOB_PIN as input for clock pulse rate knob
    pinMode(CLOCK_IN_PIN, INPUT_PULLUP); // Set CLOCK_IN_PIN as input with pullup for clock input pulses
    pinMode(CLOCK_IN_PLUG_DETECT_PIN, INPUT_PULLUP); 
    attachInterrupt(digitalPinToInterrupt(CLOCK_IN_PIN), clockInISR, RISING); // Attach interrupt for clock input pulses

    // GAMEBOY LINK
    pinMode(GB_CLOCK_PIN, OUTPUT);
    pinMode(GB_SI_PIN, INPUT);
    pinMode(GB_SO_PIN, OUTPUT);
  
    // Initialize Serial1, Serial2, and Serial3 for MIDI communication (31250 baud rate)
    Serial1.begin(31250); // Initialize UART1 for MIDIINPUT1
    Serial2.begin(31250); // Initialize UART2 for MIDIINPUT2
    Serial3.begin(31250); // Initialize UART3 for MIDIOUTPUT
  
    MIDIINPUT1.begin(MIDI_CHANNEL_OMNI);  // Listen to all MIDI channels on MIDIINPUT1
    MIDIINPUT2.begin(MIDI_CHANNEL_OMNI);  // Listen to all MIDI channels on MIDIINPUT2

    // Initialize I2C for OLED
    Wire.begin();
    display.begin(SSD1306_SWITCHCAPVCC, OLED_I2C_ADDRESS);
    display.setTextSize(1);
    display.setTextColor(SSD1306_WHITE);
    display.clearDisplay();
    display.setCursor(0, 0);
    display.print("MEGAMIDI MERGE ");
    display.print(VERSION);
    display.setCursor(0, 10);
    display.print("Initializing..");
    display.setCursor(0, 20);
    display.print("rusaaKKMODS @ 2024");
    display.display();
  
    // Set a generic handler for MIDIINPUT1 and MIDIINPUT2 to forward all messages
    MIDIINPUT1.setHandleMessage(forwardMessageInput1);
    MIDIINPUT2.setHandleMessage(forwardMessageInput2);
}

void loop() {
    handleClockOut();
    handleClockIn();
    handleDisplay();

    // Continuously read from all MIDI inputs
    MIDIINPUT1.read();
    MIDIINPUT2.read();
}

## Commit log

2024-11-11 schematic and review draft
2024-11-11 rename file arduino
2024-11-11 upload prototype foto
2024-11-15 add shcematics kicad
    [megamidimerge.csv, megamidimerge.kicad_pcb]
